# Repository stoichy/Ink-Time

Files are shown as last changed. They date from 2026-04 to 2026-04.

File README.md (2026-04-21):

# InkTime - Open Source Smartwatch

InkTime is a low-cost, open-source smartwatch designed for the **EVT (Engineering Validation Test)** phase. This project involves the full hardware design cycle, from schematic capture and PCB layout in Autodesk Fusion 360 to mechanical integration and manufacturing file generation.

<p align="center">
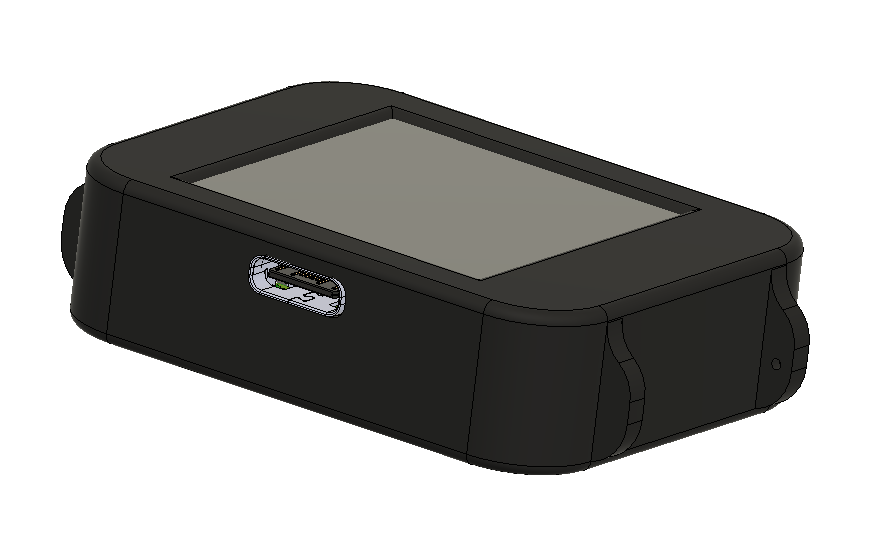
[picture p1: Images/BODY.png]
  
</p>

## Project Overview

The system architecture centers around the **nRF52840** (Nordic Semiconductor) for BLE connectivity and ultra-low power consumption, paired with a high-contrast E-Paper display.

### Key Features
- **MCU:** Nordic nRF52840 (Cortex-M4 + BLE 5.0).
- **Display:** 1.54" E-Paper (Ultra-low power, sunlight readable).
- **Power:** USB-C charging with 180mAh LiPo battery.
- **Form Factor:** Compact design ready for mechanical integration.

---

## System Architecture

### Block Diagram
<p align="center">
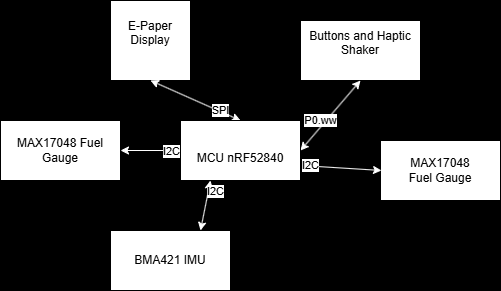
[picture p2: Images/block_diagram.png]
  
</p>
The core of the device integrates high-speed SPI for the display and I2C for peripheral sensors.

### Hardware Functionality
- **Microcontroller:** The nRF52840 provides a 2.4GHz radio and ARM® Cortex®-M4 processor.
- **Interfaces:**
  - **SPI:** Dedicated for the E-Ink display to ensure high-speed data transfer.
  - **I2C:** Connects the IMU (Inertial Measurement Unit) and Fuel Gauge for battery monitoring.
  - **GPIO:** Used for tactile buttons and the haptic shaker motor (PWM controlled).
- **Power System:** Charged via USB-C (5V), regulated to 3.3V via a low-dropout (LDO) regulator.

---

## Bill of Materials (BOM)

| Component | Value/Model | Package | Provider (JLC) | Datasheet |
| :--- | :--- | :--- | :--- | :--- |
| **MCU** | nRF52840a | QFN™73 | [JLC Part](https://jlcpcb.com/) | [Link](https://infocenter.nordicsemi.com/pdf/nRF52840_PS_v1.1.pdf) |
| **Display** | E-Paper 1.54" | FPC | [JLC Part](https://jlcpcb.com/) | [Link](#) |
| **Charger IC** | MCP73832 | SOT-23-5 | [JLC Part](https://jlcpcb.com/) | [Link](https://ww1.microchip.com/downloads/en/DeviceDoc/20001984g.pdf) |
| **Battery** | LiPo 180mAh | Custom | N/A | [Link](#) |
| **LDO** | 3.3V Regulator | SOT-23 | [JLC Part](https://jlcpcb.com/) | [Link](#) |

---

## Pinout Mapping

| nRF52840 Pin | Function | Description |
| :--- | :--- | :--- |
| **P0.xx** | SPI_SCK | Serial Clock for E-Ink |
| **P0.yy** | SPI_MOSI | Master Out Slave In for E-Ink |
| **P0.zz** | I2C_SDA | Data line for Sensors |
| **P0.ww** | PWM_VIB | Haptic motor control |

---

## Energy Budget

- **Battery Capacity:** 180 mAh.
- **Deep Sleep Mode:** Estimated < 50 µA.
- **Active Refresh:** ~8-12 mA (peak during E-Ink refresh).
- **Estimated Standby:** Approx. 10-14 days.

---

## Design Log & Constraints

### PCB Implementation
- **Layers:** 2-layer design (Top/Bottom) with dedicated ground planes.
- **Trace Widths:** Power (0.3mm), Signal (0.15mm) to comply with JLC manufacturing standards.
- **Decoupling:** 100nF capacitors (0201) placed close to MCU VCC pins.

<p align="center">
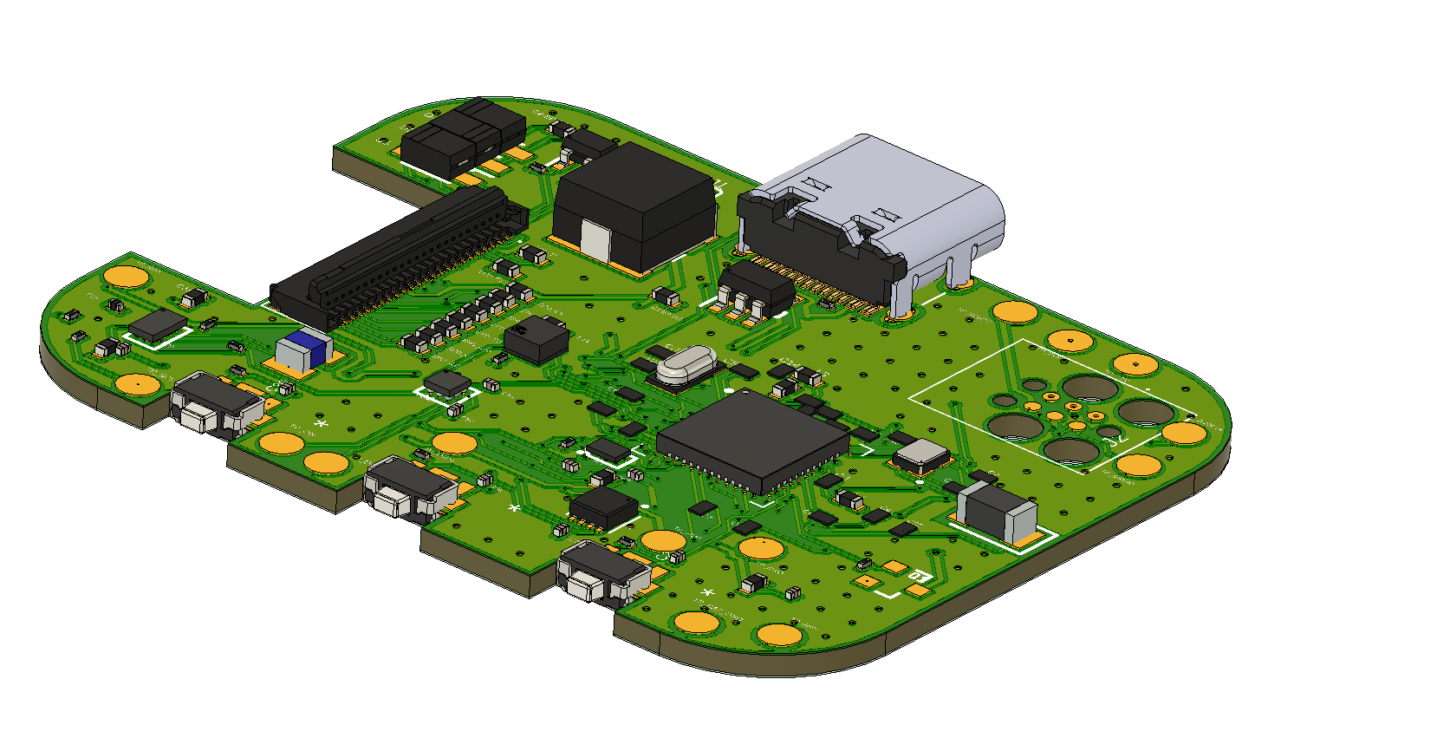
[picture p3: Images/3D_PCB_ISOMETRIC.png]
InkTime PCB Layout
  
</p>

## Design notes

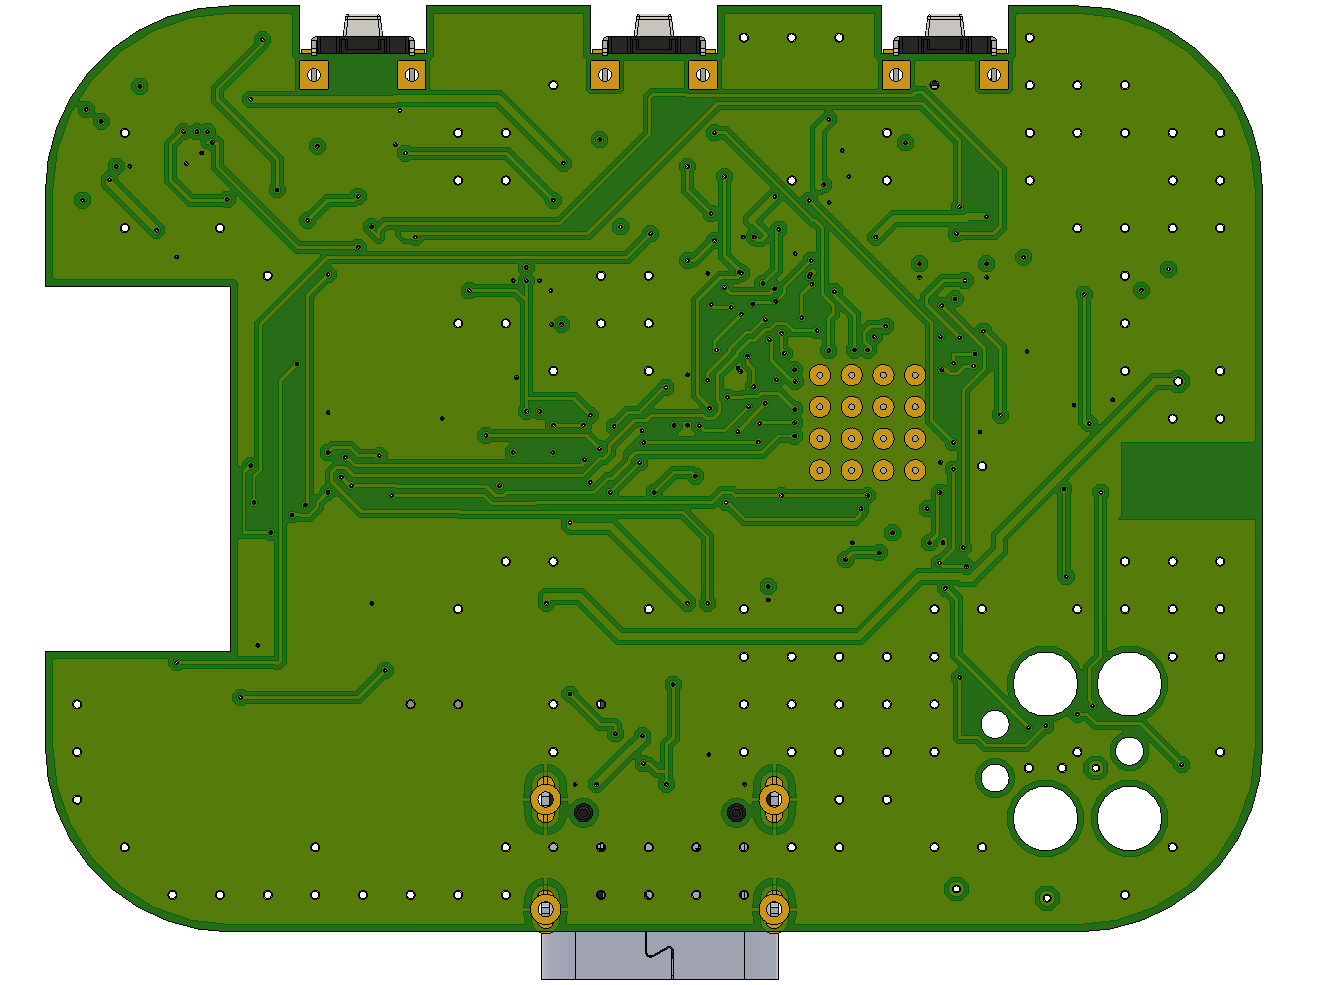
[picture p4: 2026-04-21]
Images/3D_PCB_BACK.png

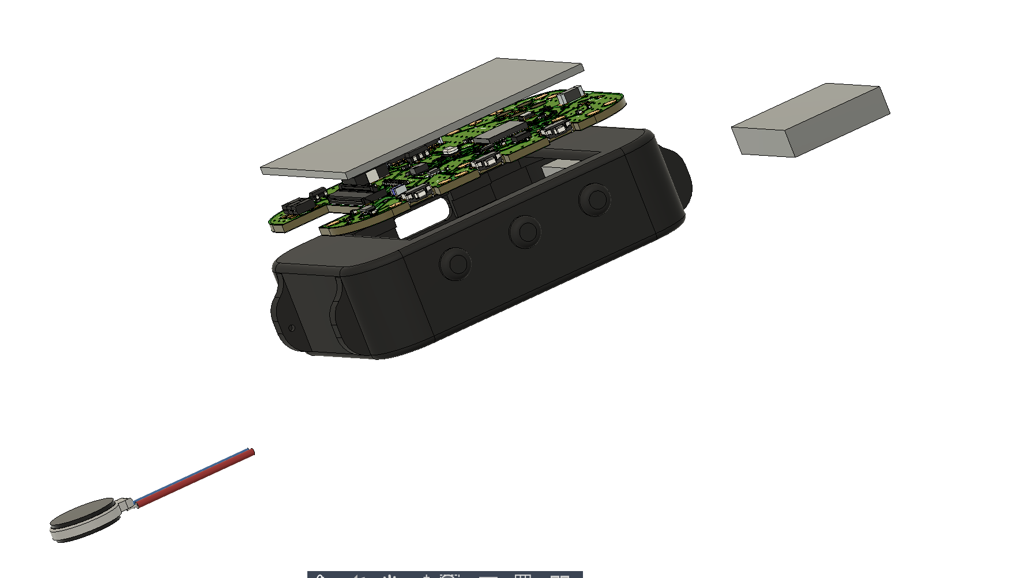
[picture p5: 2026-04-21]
Images/EXPLODED_VIEW.png

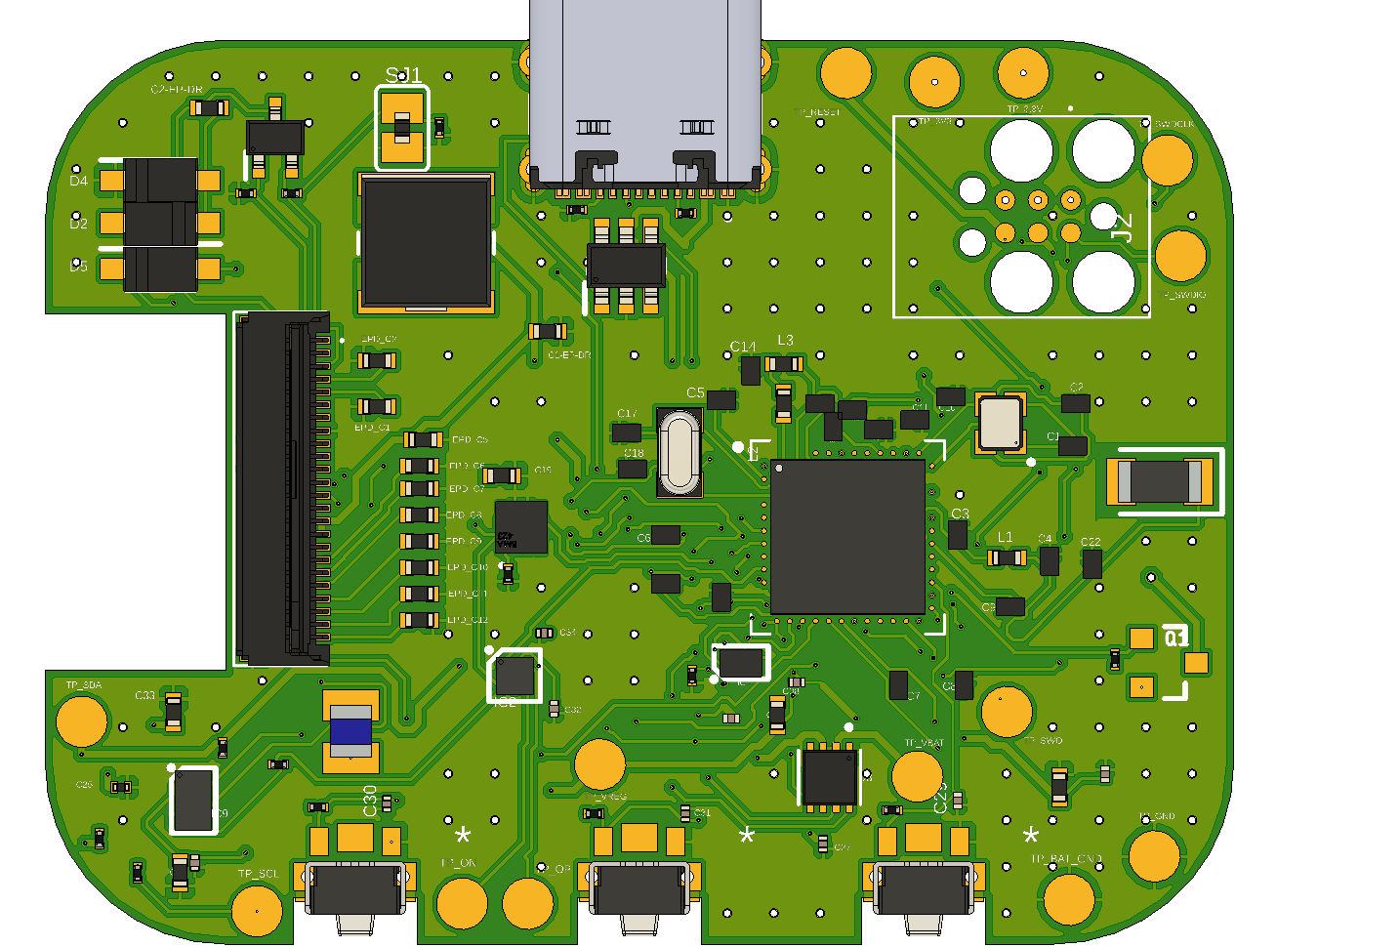
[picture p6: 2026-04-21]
Images/3D_PCB_FRONT.png

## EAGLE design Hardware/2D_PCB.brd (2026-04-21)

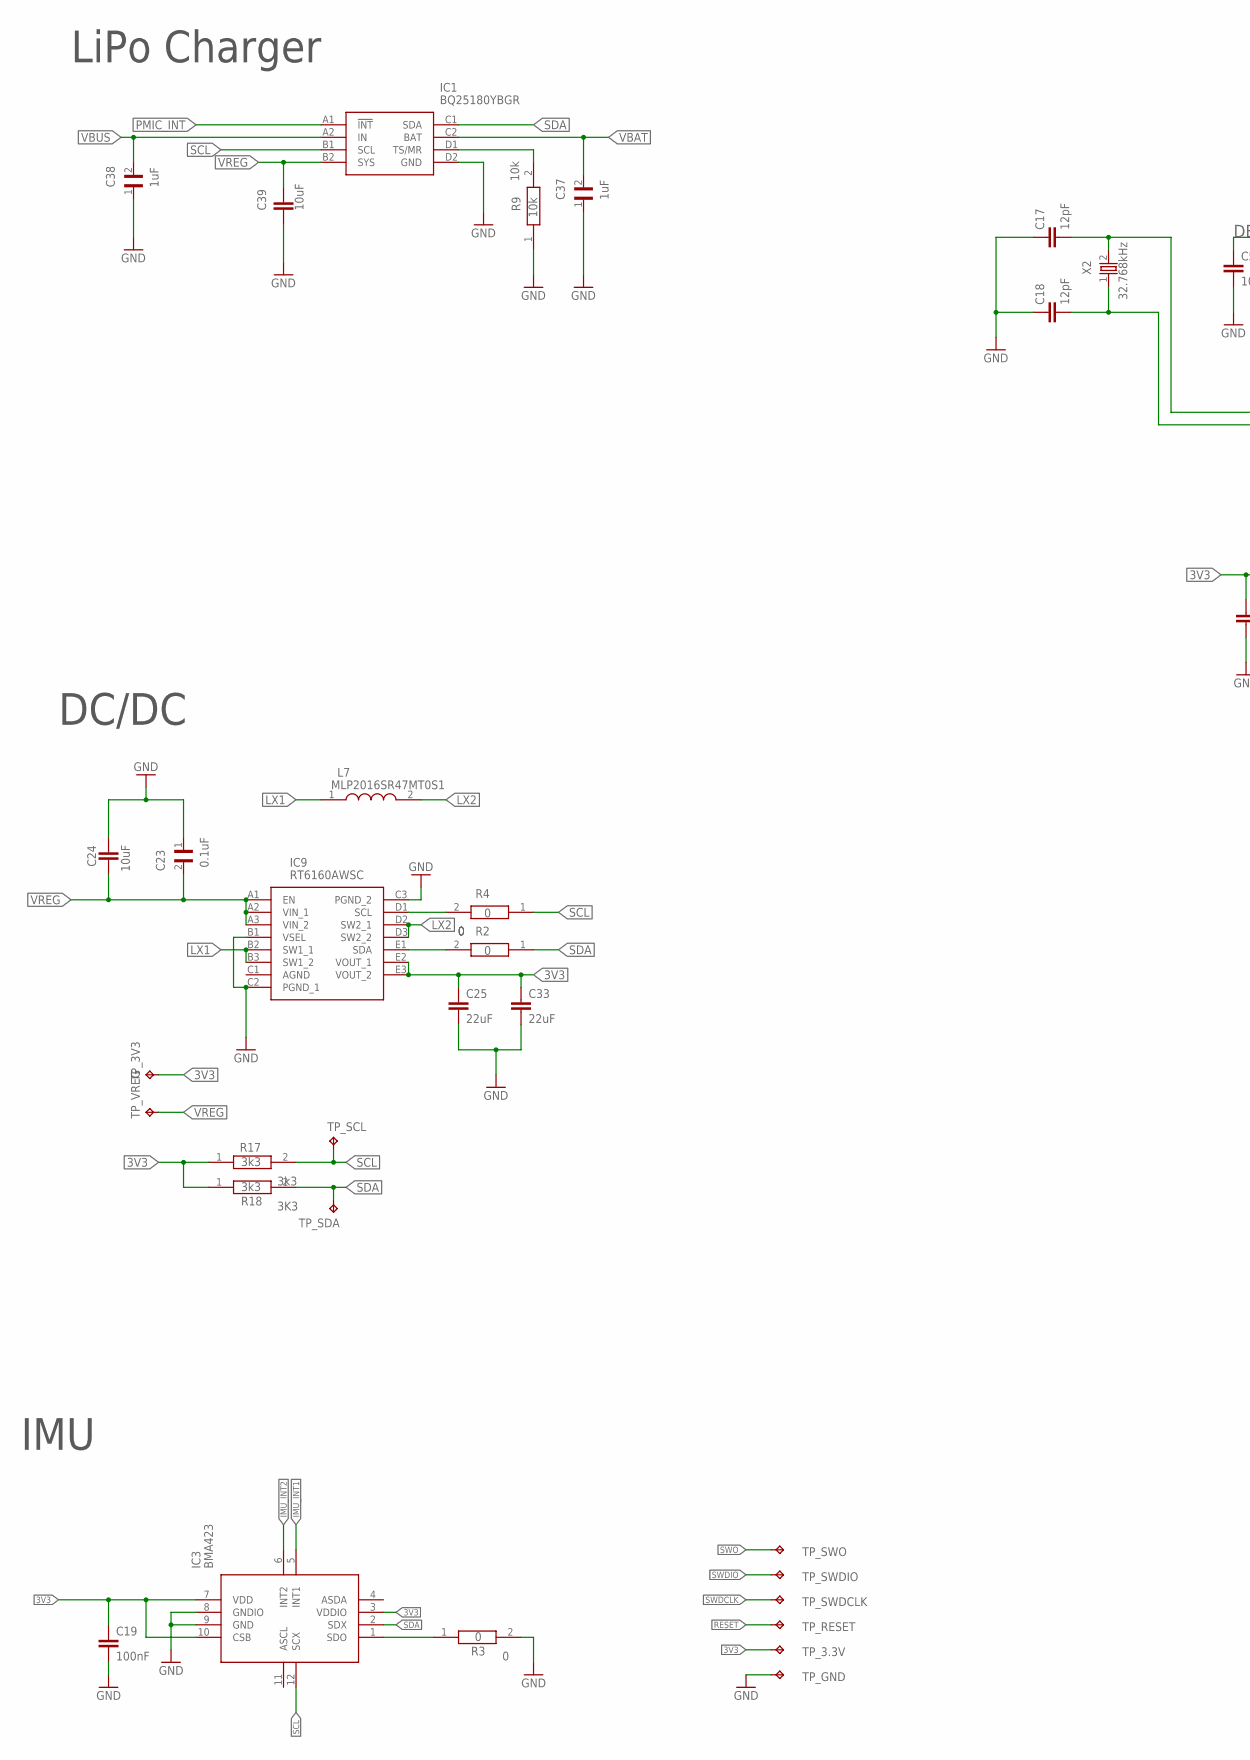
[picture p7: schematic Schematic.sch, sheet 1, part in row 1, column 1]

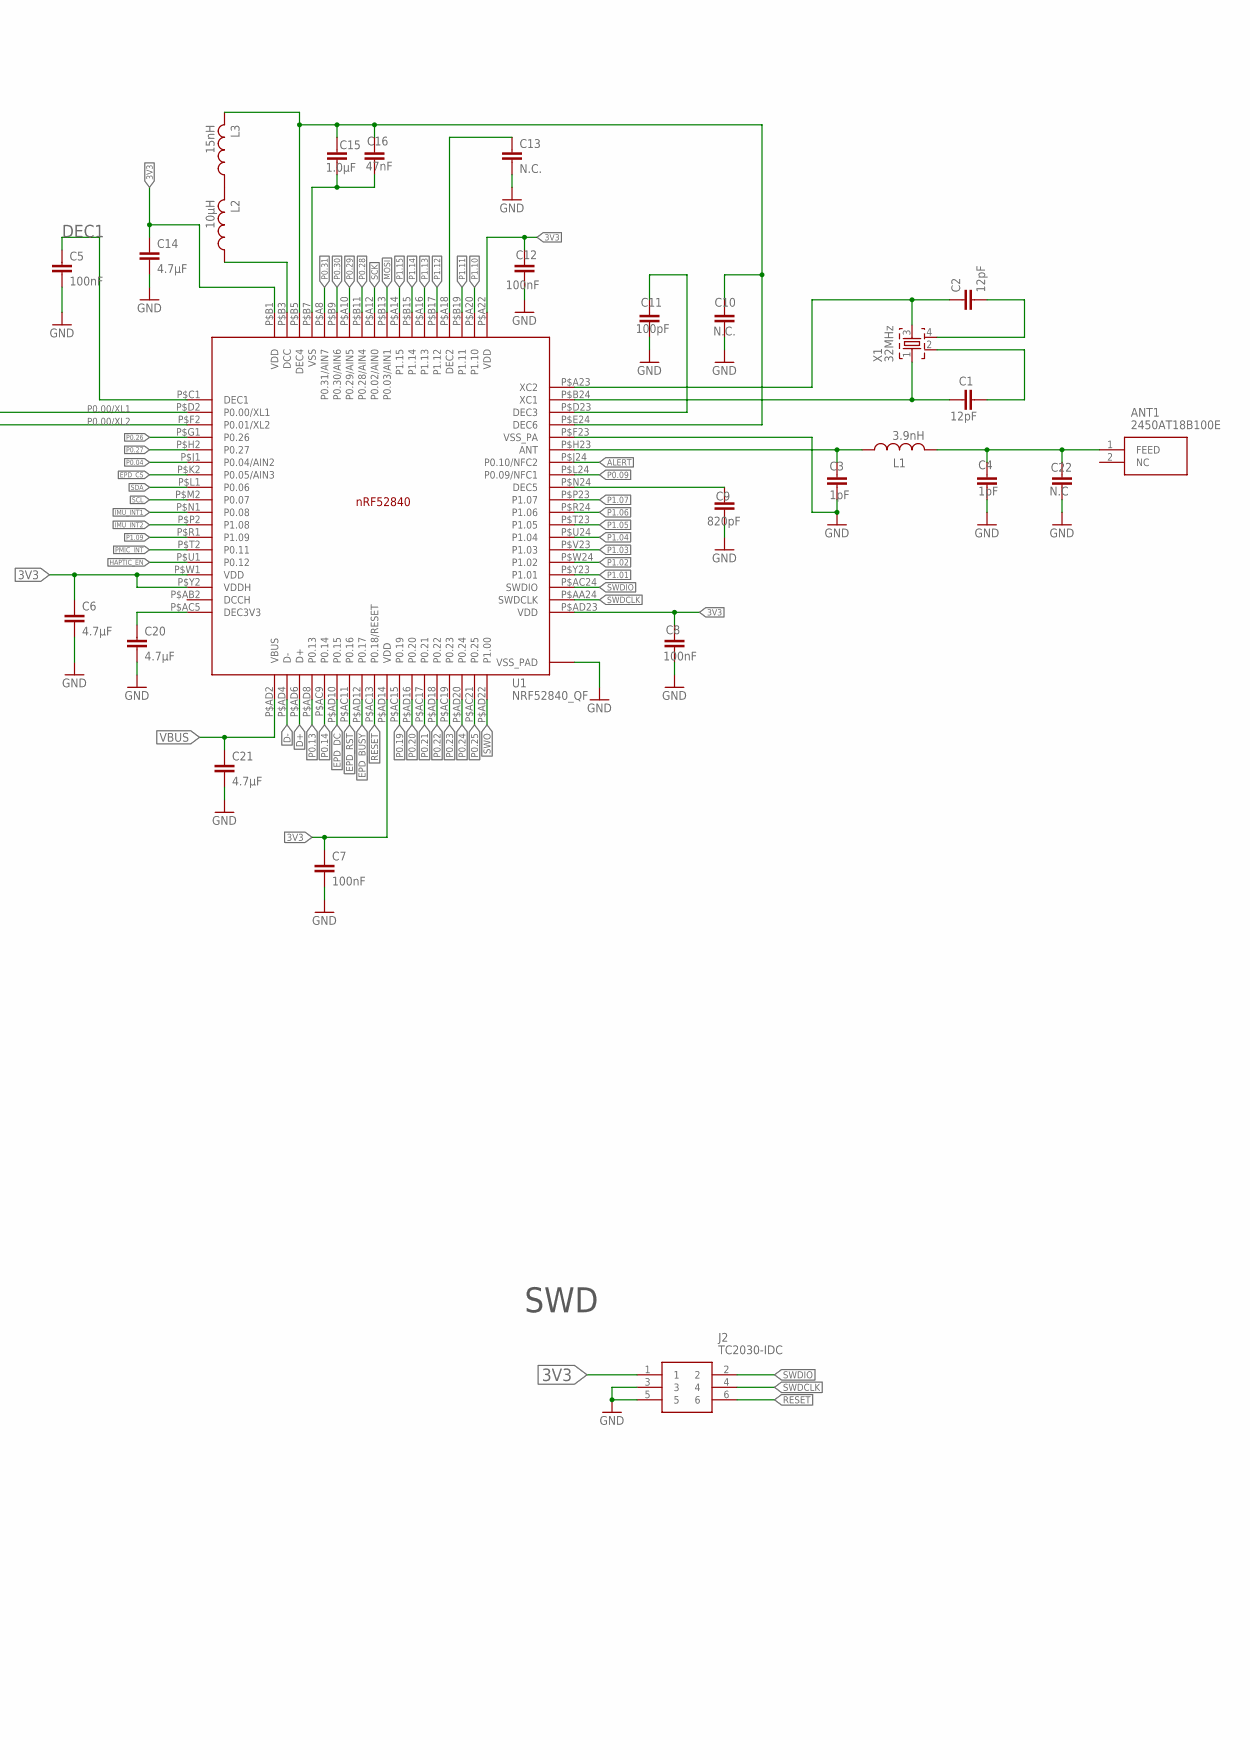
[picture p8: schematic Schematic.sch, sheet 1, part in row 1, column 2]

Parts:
ANT1: 2450AT18B100E; 2450AT18B100E_ANTC3216X140N
C1, C2, C17, C18: 12pF; NORDIC_NRF_3_RESC0201_L
C3, C4: 1pF; NORDIC_NRF_3_RESC0201_L
C5, C7, C8, C12: 100nF; NORDIC_NRF_3_RESC0201_L
C6, C14, C20, C21: 4.7µF; NORDIC_NRF_3_RESC0201_L
C9: 820pF; NORDIC_NRF_3_RESC0201_L
C10, C13: N.C.; NORDIC_NRF_3_RESC0201_L
C11: 100pF; NORDIC_NRF_3_RESC0201_L
C15: 1.0µF; NORDIC_NRF_3_RESC0201_L
C16: 47nF; NORDIC_NRF_3_RESC0201_L
C19: 100nF; NORDIC_NRF_3_RESC0402_L
C22: N.C; NORDIC_NRF_3_RESC0201_L
C23: 0.1uF; GRM011R60J152KE01L_2_CAPC0201X13N
C24, C39: 10uF; NORDIC_NRF_3_RESC0402_L
C25: 22uF; NORDIC_NRF_3_RESC0201_L
C33: 22uF; NORDIC_NRF_3_RESC0402_L
C37, C38: 1uF; GRM011R60J152KE01L_2_CAPC0201X13N
IC1: BQ25180YBGR; BQ25180YBGR_BGA8C40P2X4_100X155X50
IC3: BMA423; BMA423_BMA423
IC9: RT6160AWSC; RT6160AWSC_BGA15C40P3X5_140X230X60
J2: TC2030-IDC; TC2030-IDC_TC2030IDC
L1: 3.9nH; NORDIC_NRF_2_RESC0402_L
L2: 10µH; NORDIC_NRF_2_RESC0402_L
L3: 15nH; NORDIC_NRF_2_RESC0402_L
L7: MLP2016SR47MT0S1; MLP2016SR47MT0S1_INDC2016X100N
R2, R3, R4: 0; ERA-1AEB3401C_0201
R9: 10k; ERA-1AEB3401C_0201
R17: 3k3; ERA-1AEB3401C_0201
R18: 3K3; ERA-1AEB3401C_0201
TP_3.3V, TP_3V3: HECTOR_WATCH_1_TPTP20R; HECTOR_WATCH_1_TP20R
TP_GND: HECTOR_WATCH_1_TPTP20R; HECTOR_WATCH_1_TP20R
TP_RESET: HECTOR_WATCH_1_TPTP20R; HECTOR_WATCH_1_TP20R
TP_SCL: HECTOR_WATCH_1_TPTP20R; HECTOR_WATCH_1_TP20R
TP_SDA: HECTOR_WATCH_1_TPTP20R; HECTOR_WATCH_1_TP20R
TP_SWDCLK: HECTOR_WATCH_1_TPTP20R; HECTOR_WATCH_1_TP20R
TP_SWDIO: HECTOR_WATCH_1_TPTP20R; HECTOR_WATCH_1_TP20R
TP_SWO: HECTOR_WATCH_1_TPTP20R; HECTOR_WATCH_1_TP20R
TP_VREG: HECTOR_WATCH_1_TPTP20R; HECTOR_WATCH_1_TP20R
U1: NRF52840_QF; NORDIC_NRF_4_AQFN50P700X700X85_HS-74N
X1: 32MHz; NORDIC_NRF_BT-XTAL_2016_N
X2: 32.768kHz; NORDIC_NRF_1_XTAL_3215_N

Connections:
3V3: C6.1, C7.1, C8.1, C12.1, C14.1, C19.1, C25.1, C33.1, IC3.3 (VDDIO), IC3.7 (VDD), IC3.10 (CSB), IC9.E2 (VOUT_1), IC9.E3 (VOUT_2), J2.1, R17.1, R18.1, TP_3.3V.TP, TP_3V3.TP, U1.P$A22 (VDD), U1.P$AD14 (VDD), U1.P$AD23 (VDD), U1.P$B1 (VDD), U1.P$W1 (VDD), U1.P$Y2 (VDDH); also elsewhere on the board
ALERT: U1.P$J24 (P0.10/NFC2); also elsewhere on the board
D+: U1.P$AD6 (D+); also elsewhere on the board
D-: U1.P$AD4 (D-); also elsewhere on the board
DEC1: C5.1, U1.P$C1 (DEC1)
EPD_BUSY: U1.P$AD12 (P0.17); also elsewhere on the board
EPD_CS: U1.P$K2 (P0.05/AIN3); also elsewhere on the board
EPD_DC: U1.P$AD10 (P0.15); also elsewhere on the board
EPD_RST: U1.P$AC11 (P0.16); also elsewhere on the board
GND: C3.2, C4.2, C5.2, C6.2, C7.2, C8.2, C9.2, C10.2, C11.2, C12.2, C13.2, C14.2, C17.1, C18.1, C19.2, C20.2, C21.2, C22.2, C23.1, C24.1, C25.2, C33.2, C37.1, C38.1, C39.2, IC1.D2 (GND), IC3.8 (GNDIO), IC3.9 (GND), IC9.B1 (VSEL), IC9.C2 (PGND_1), IC9.C3 (PGND_2), J2.3, J2.5, R3.2, R9.1, TP_GND.TP, U1.P$74 (VSS_PAD), U1.P$75 (VSS_PAD), U1.P$76 (VSS_PAD), U1.P$77 (VSS_PAD), U1.P$78 (VSS_PAD), U1.P$79 (VSS_PAD), U1.P$80 (VSS_PAD), U1.P$81 (VSS_PAD), U1.P$82 (VSS_PAD), U1.P$83 (VSS_PAD), U1.P$84 (VSS_PAD), U1.P$85 (VSS_PAD), U1.P$86 (VSS_PAD), U1.P$87 (VSS_PAD), U1.P$88 (VSS_PAD), U1.P$89 (VSS_PAD), U1.P$90 (VSS_PAD), U1.P$F23 (VSS_PA); also elsewhere on the board
HAPTIC_EN: U1.P$U1 (P0.12); also elsewhere on the board
IMU_INT1: IC3.5 (INT1), U1.P$N1 (P0.08)
IMU_INT2: IC3.6 (INT2), U1.P$P2 (P1.08)
LX1: IC9.B2 (SW1_1), IC9.B3 (SW1_2), L7.1
LX2: IC9.D2 (SW2_1), IC9.D3 (SW2_2), L7.2
MOSI: U1.P$B13 (P0.03/AIN1); also elsewhere on the board
unnamed: C20.1, U1.P$AC5 (DEC3V3)
unnamed: IC1.D1 (TS/MR), R9.2
unnamed: C9.1, U1.P$N24 (DEC5)
unnamed: C3.1, L1.1, U1.P$H23 (ANT)
unnamed: IC9.D1 (SCL), R4.2
unnamed: ANT1.1 (FEED), C4.1, C22.1, L1.2
unnamed: IC9.E1 (SDA), R2.2
unnamed: C10.1, C15.1, C16.1, L3.2, U1.P$B5 (DEC4), U1.P$E24 (DEC6)
unnamed: IC3.1 (SDO), R3.1
unnamed: C11.1, U1.P$D23 (DEC3)
unnamed: C2.1, U1.P$A23 (XC2), X1.3
unnamed: C2.2, X1.4
unnamed: C1.2, X1.2
unnamed: C1.1, U1.P$B24 (XC1), X1.1
unnamed: L2.2, L3.1
unnamed: C13.1, U1.P$A18 (DEC2)
unnamed: C15.2, C16.2, U1.P$B7 (VSS)
unnamed: L2.1, U1.P$B3 (DCC)
P0.00/XL1: C17.2, U1.P$D2 (P0.00/XL1), X2.2
P0.00/XL2: C18.2, U1.P$F2 (P0.01/XL2), X2.1
P0.04: U1.P$J1 (P0.04/AIN2)
P0.09: U1.P$L24 (P0.09/NFC1)
P0.13: U1.P$AD8 (P0.13); also elsewhere on the board
P0.14: U1.P$AC9 (P0.14); also elsewhere on the board
P0.19: U1.P$AC15 (P0.19)
P0.20: U1.P$AD16 (P0.20)
P0.21: U1.P$AC17 (P0.21)
P0.22: U1.P$AD18 (P0.22)
P0.23: U1.P$AC19 (P0.23)
P0.24: U1.P$AD20 (P0.24)
P0.25: U1.P$AC21 (P0.25)
P0.26: U1.P$G1 (P0.26)
P0.27: U1.P$H2 (P0.27)
P0.28: U1.P$B11 (P0.28/AIN4)
P0.29: U1.P$A10 (P0.29/AIN5)
P0.30: U1.P$B9 (P0.30/AIN6)
P0.31: U1.P$A8 (P0.31/AIN7)
P1.01: U1.P$Y23 (P1.01); also elsewhere on the board
P1.02: U1.P$W24 (P1.02); also elsewhere on the board
P1.03: U1.P$V23 (P1.03)
P1.04: U1.P$U24 (P1.04)
P1.05: U1.P$T23 (P1.05)
P1.06: U1.P$R24 (P1.06)
P1.07: U1.P$P23 (P1.07)
P1.09: U1.P$R1 (P1.09)
P1.10: U1.P$A20 (P1.10)
P1.11: U1.P$B19 (P1.11)
P1.12: U1.P$B17 (P1.12)
P1.13: U1.P$A16 (P1.13)
P1.14: U1.P$B15 (P1.14)
P1.15: U1.P$A14 (P1.15)
PMIC_INT: IC1.A1 (!INT), U1.P$T2 (P0.11)
RESET: J2.6, TP_RESET.TP, U1.P$AC13 (P0.18/RESET)
SCK: U1.P$A12 (P0.02/AIN0); also elsewhere on the board
SCL: IC1.B1 (SCL), IC3.12 (SCX), R4.1, R17.2, TP_SCL.TP, U1.P$M2 (P0.07); also elsewhere on the board
SDA: IC1.C1 (SDA), IC3.2 (SDX), R2.1, R18.2, TP_SDA.TP, U1.P$L1 (P0.06); also elsewhere on the board
SWDCLK: J2.4, TP_SWDCLK.TP, U1.P$AA24 (SWDCLK)
SWDIO: J2.2, TP_SWDIO.TP, U1.P$AC24 (SWDIO)
SWO: TP_SWO.TP, U1.P$AD22 (P1.00)
VBAT: C37.2, IC1.C2 (BAT); also elsewhere on the board
VBUS: C21.1, C38.2, IC1.A2 (IN), U1.P$AD2 (VBUS); also elsewhere on the board
VREG: C23.2, C24.2, C39.1, IC1.B2 (SYS), IC9.A1 (EN), IC9.A2 (VIN_1), IC9.A3 (VIN_2), TP_VREG.TP

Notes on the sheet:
DC/DC
LiPo Charger
IMU
SWD

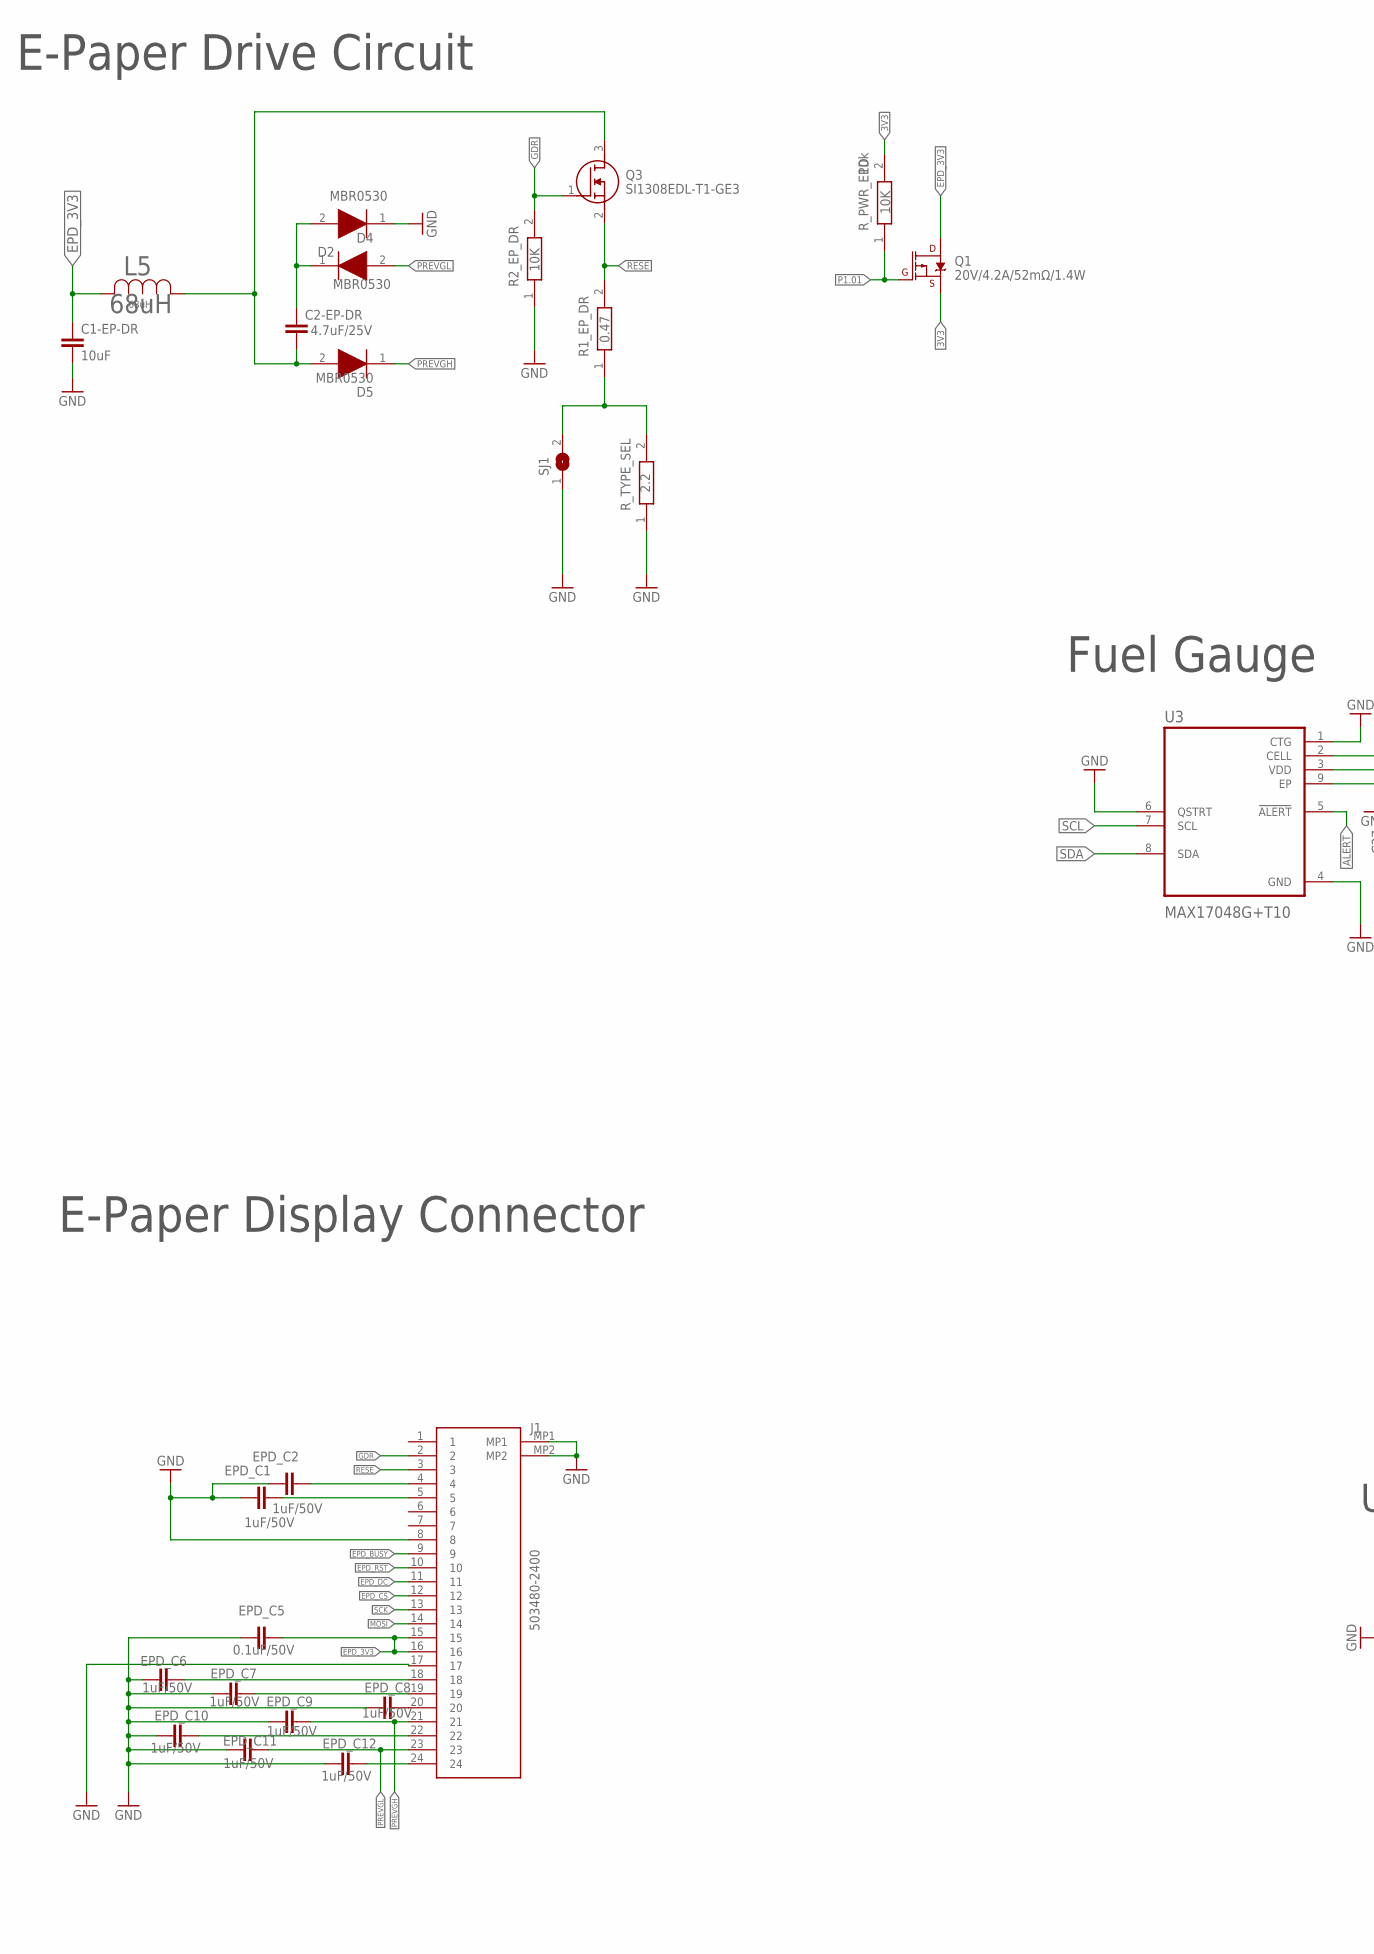
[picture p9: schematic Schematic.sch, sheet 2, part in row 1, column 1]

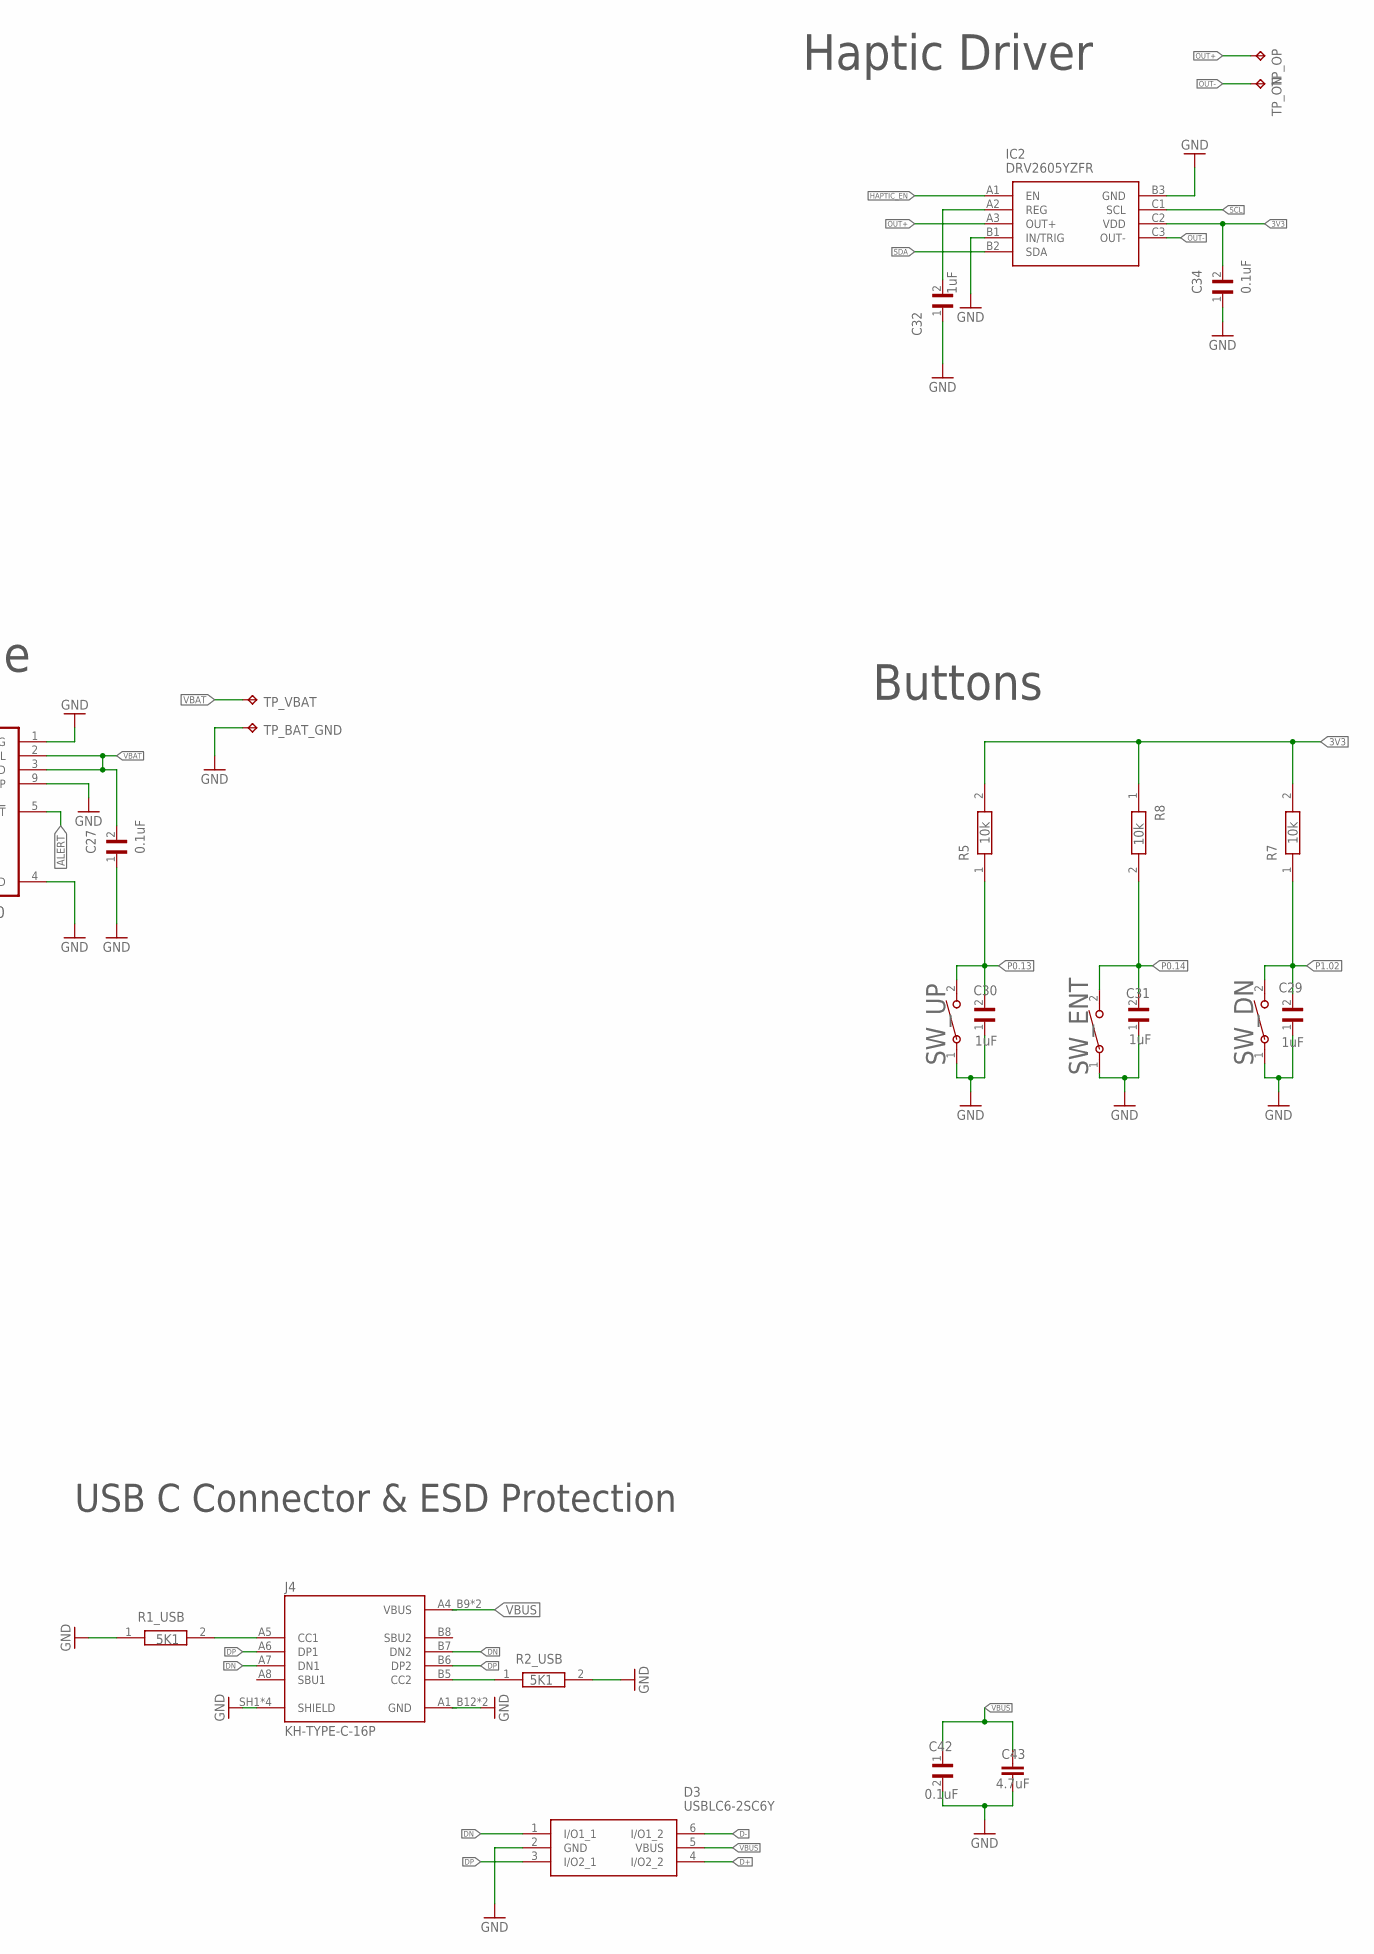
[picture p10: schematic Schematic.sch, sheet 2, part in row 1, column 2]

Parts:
C1-EP-DR: 10uF; NORDIC_NRF_3_RESC0402_L
C2-EP-DR: 4.7uF/25V; NORDIC_NRF_3_RESC0402_L
C27, C34, C42: 0.1uF; GRM011R60J152KE01L_2_CAPC0201X13N
C29, C30, C31, C32: 1uF; GRM011R60J152KE01L_2_CAPC0201X13N
C43: 4.7uF; NORDIC_NRF_3_RESC0402_L
D2, D4, D5: MBR0530; ESP32_C6_LIBRARY_5_SOD3716X135N
D3: USBLC6-2SC6Y; ESP32_C6_LIBRARY_3_SOT95P280X145-6N
EPD_C1, EPD_C2, EPD_C6, EPD_C7, EPD_C8, EPD_C9, EPD_C10, EPD_C11, EPD_C12: 1uF/50V; NORDIC_NRF_3_RESC0402_L
EPD_C5: 0.1uF/50V; NORDIC_NRF_3_RESC0402_L
IC2: DRV2605YZFR; DRV2605YZFR_BGA9C50P3X3_144X144X62
J1: 503480-2400; 503480-2400_5034802400
J4: KH-TYPE-C-16P; KH-TYPE-C-16P_KINGHELM_KH-TYPE-C-16P
L5: 68uH; ESP32_C6_LIBRARY_2_IND_4828-WE-TPC_WRE
Q1: 20V/4.2A/52mΩ/1.4W; ESP32_C6_LIBRARY_4_ESP32_C6_LIBRARY_4_ESP32_C6_LIBRARY_4_ES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
Q3: SI1308EDL-T1-GE3; ESP32_C6_LIBRARY_6_SOT65P210X110-3N
R1_EP_DR: 0.47; ERA-1AEB3401C_0201
R1_USB, R2_USB: 5K1; ERA-1AEB3401C_0201
R2_EP_DR: 10K; ERA-1AEB3401C_0201
R5, R7, R8: 10k; ERA-1AEB3401C_0201
R_PWR_EPD: 10k; ERA-1AEB3401C_0201
R_TYPE_SEL: 2.2; ERA-1AEB3401C_0201
SJ1: ESP32_C6_LIBRARY_7_JUMPER_SJ
SW_DN: 2025-10-22_07-23-44_LIBRARY_EVP-AKE31ASW_EVP-AKE3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; 2025-10-22_07-23-44_LIBRARY_SW_EVP-AKE31A_PAN
SW_ENT: 2025-10-22_07-23-44_LIBRARY_EVP-AKE31ASW_EVP-AKE3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; 2025-10-22_07-23-44_LIBRARY_SW_EVP-AKE31A_PAN
SW_UP: 2025-10-22_07-23-44_LIBRARY_EVP-AKE31ASW_EVP-AKE3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; 2025-10-22_07-23-44_LIBRARY_SW_EVP-AKE31A_PAN
TP_BAT_GND: HECTOR_WATCH_1_TPTP20R; HECTOR_WATCH_1_TP20R
TP_ON: HECTOR_WATCH_1_TPTP20R; HECTOR_WATCH_1_TP20R
TP_OP: HECTOR_WATCH_1_TPTP20R; HECTOR_WATCH_1_TP20R
TP_VBAT: HECTOR_WATCH_1_TPTP20R; HECTOR_WATCH_1_TP20R
U3: MAX17048G+T10; ESP32_C6_LIBRARY_SON50P200X200X80-9N

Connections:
3V3: C34.2, IC2.C2 (VDD), Q1.2 (S), R5.2, R7.2, R8.1, R_PWR_EPD.2; also elsewhere on the board
ALERT: U3.5 (!ALERT); also elsewhere on the board
D+: D3.4 (I/O2_2); also elsewhere on the board
D-: D3.6 (I/O1_2); also elsewhere on the board
DN: D3.1 (I/O1_1), J4.A7 (DN1), J4.B7 (DN2)
DP: D3.3 (I/O2_1), J4.A6 (DP1), J4.B6 (DP2)
EPD_3V3: C1-EP-DR.1, EPD_C5.2, J1.15, J1.16, L5.2, Q1.3 (D)
EPD_BUSY: J1.9; also elsewhere on the board
EPD_CS: J1.12; also elsewhere on the board
EPD_DC: J1.11; also elsewhere on the board
EPD_RST: J1.10; also elsewhere on the board
GDR: J1.2, Q3.1 (G), R2_EP_DR.2
GND: C1-EP-DR.2, C27.1, C29.1, C30.1, C31.1, C32.1, C34.1, C42.2, C43.2, D3.2 (GND), D4.1 (K), EPD_C1.1, EPD_C2.1, EPD_C5.1, EPD_C6.1, EPD_C7.1, EPD_C8.1, EPD_C9.1, EPD_C10.1, EPD_C11.1, EPD_C12.1, IC2.B1 (IN/TRIG), IC2.B3 (GND), J1.8, J1.17, J1.MP1, J1.MP2, J4.A1_B12 (GND), J4.A12_B1 (GND), J4.SH1 (SHIELD), J4.SH2 (SHIELD), J4.SH3 (SHIELD), J4.SH4 (SHIELD), R1_USB.1, R2_EP_DR.1, R2_USB.2, R_TYPE_SEL.1, SJ1.1, SW_DN.1, SW_ENT.1, SW_UP.1, TP_BAT_GND.TP, U3.1 (CTG), U3.4 (GND), U3.6 (QSTRT), U3.9 (EP); also elsewhere on the board
HAPTIC_EN: IC2.A1 (EN); also elsewhere on the board
MOSI: J1.14; also elsewhere on the board
unnamed: C2-EP-DR.2, D5.2 (A), L5.1, Q3.3 (D)
unnamed: C2-EP-DR.1, D2.1 (K), D4.2 (A)
unnamed: R1_EP_DR.1, R_TYPE_SEL.2, SJ1.2
unnamed: J4.A5 (CC1), R1_USB.2
unnamed: EPD_C8.2, J1.20
unnamed: EPD_C2.2, J1.4
unnamed: EPD_C1.2, J1.5
unnamed: EPD_C6.2, J1.18
unnamed: EPD_C7.2, J1.19
unnamed: C32.2, IC2.A2 (REG)
unnamed: EPD_C10.2, J1.22
unnamed: EPD_C12.2, J1.24
unnamed: J4.B5 (CC2), R2_USB.1
OUT+: IC2.A3 (OUT+), TP_OP.TP
OUT-: IC2.C3 (OUT-), TP_ON.TP
P0.13: C30.2, R5.1, SW_UP.2; also elsewhere on the board
P0.14: C31.2, R8.2, SW_ENT.2; also elsewhere on the board
P1.01: Q1.1 (G), R_PWR_EPD.1; also elsewhere on the board
P1.02: C29.2, R7.1, SW_DN.2; also elsewhere on the board
PREVGH: D5.1 (K), EPD_C9.2, J1.21
PREVGL: D2.2 (A), EPD_C11.2, J1.23
RESE: J1.3, Q3.2 (S), R1_EP_DR.2
SCK: J1.13; also elsewhere on the board
SCL: IC2.C1 (SCL), U3.7 (SCL); also elsewhere on the board
SDA: IC2.B2 (SDA), U3.8 (SDA); also elsewhere on the board
VBAT: C27.2, TP_VBAT.TP, U3.2 (CELL), U3.3 (VDD); also elsewhere on the board
VBUS: C42.1, C43.1, D3.5 (VBUS), J4.A4_B9 (VBUS), J4.A9_B4 (VBUS); also elsewhere on the board

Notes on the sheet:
E-Paper Drive Circuit
E-Paper Display Connector
Fuel Gauge
USB C Connector & ESD Protection
Buttons
Haptic Driver

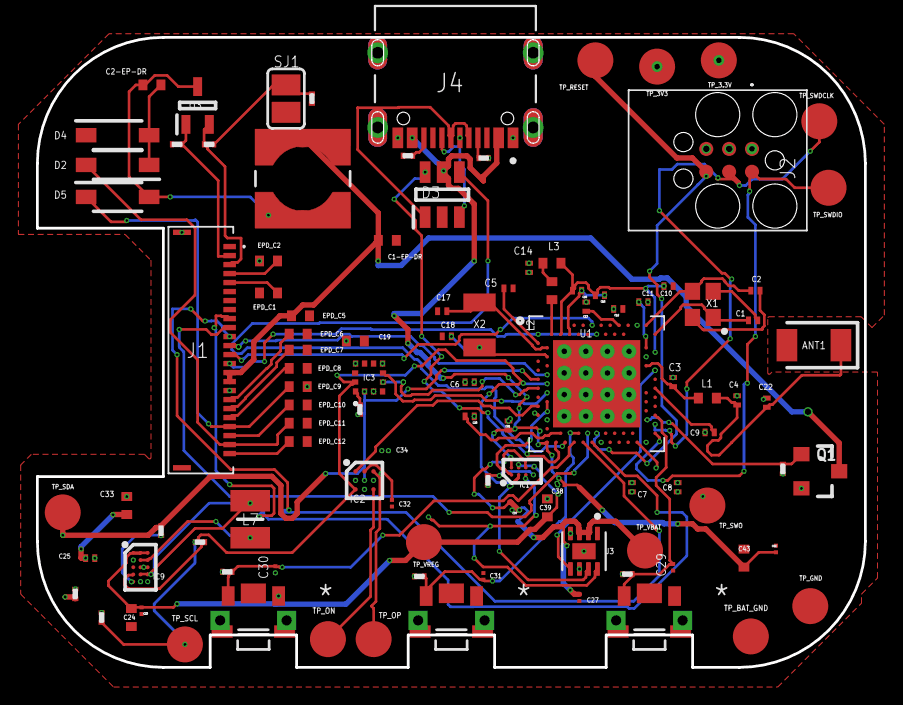
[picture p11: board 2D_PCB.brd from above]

Board: 4 copper layers, 46.0 x 35.0 mm, 105 parts (0 on the bottom side), 73 nets.

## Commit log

2026-04-10 Add Fusion Project
    Added all project files into the repository, including some screenshots
    [BOM_InkTime.csv, InkTime.brd, InkTime.sch]
2026-04-18 Corrected schematic layout within frame
    Added a standard frame and aligned components to the sheet origin. Fixes #1
    [InkTime.sch, Schematic.sch]
2026-04-18 Update Schematic.sch
    Fixed the values of the following components:
    - ANT1
    - IC3
    - IC1
    - J2
    Please let me know if there are any other incorrect values by opening another issue.
    Fixes #4
    [Schematic.sch]
2026-04-18 Fix added wire
    Removed added wire on MP1 pin of J1 component.
    Fixes #5
    [Schematic.sch]
2026-04-18 Display resistors and capacitor value
    Displayed the values of resistors and capacitors so as to ensure a more readable schematic.
    [Schematic.sch]
2026-04-18 Revert "Display resistors and capacitor value"
    This reverts commit e3d6df2a964783730cc62ca4a1df47b7156c4929.
    [Schematic.sch]
2026-04-18 Display resistors and capacitor value
    Fixes #7
    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
    [Schematic.sch]
2026-04-18 Fix copper wire position
    Completely overhauled the PCB routing design so as to separate the antenna from the rest of the layout.
    Fixes #8
    [InkTime.brd, PCB.brd]
2026-04-18 Overhaul Silkscreen readability
    Changed all components names in the layout into smaller and more readable versions.
    Fixes #12
    [PCB.brd]
2026-04-21 Add 3D Models for all components
    Added 3d Components for all PCB components along with different perspectives for the shell of the watch. Also fixed several issues with the layout.
    Fixes #13
    [2D_PCB.brd, BOM_InkTime.csv, PCB.brd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]
2026-04-21 Replace PCB image with 3D isometric version
    Updated PCB layout image to 3D isometric view.

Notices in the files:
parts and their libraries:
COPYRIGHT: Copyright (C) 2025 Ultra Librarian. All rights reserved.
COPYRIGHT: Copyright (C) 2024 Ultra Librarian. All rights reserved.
